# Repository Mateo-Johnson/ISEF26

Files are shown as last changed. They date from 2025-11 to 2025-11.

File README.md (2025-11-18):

Quad Chart

# **EDGE-A/B Overall Design (ESP32-S3-WROOM-1-N16R8)**

**EDGE-A (Expanded Model, General):**

* Dual CPU/MCU System  
  * EDGE-A uses a single ESP32-S3 and a single RP2350 dual-core ARM Cortex-M0+, with the S3 handling high-level coordination, wireless communication (WiFi/Bluetooth), audio processing, data logging, user interface, and system management, while the RP2350 serves as the dedicated real-time processing unit for precise motor control, quadrature encoder processing, sensor fusion (gyroscope \+ TOF), PWM generation, and all timing-critical operations.  
  * The two will communicate over dedicated high speed UART  
* **ESP32-S3 based (ESP32-S3-WROOM-1)**  
  * N16R8  
  * 2.4 GHz Wifi (802.11 b/g/n)  
  * Bluetooth 5.0 (LE)  
  * USB-C (USB4085-GF-A)  
  * Interrupt-capable GPIO pins for encoders/switches  
    * Analog comparators for limit switches  
    * Hardware quadrature encoder inputs (4 channels)  
  * Low-power sleep modes  
    * Light Sleep Mode  
      * CPU is paused, RTC and ULP co-processor are running.  
      * Peripherals (like WiFi, BT) can stay connected.  
      * Wakeup sources: Timer, GPIO, ULP, etc.  
      * Lower power consumption than active mode.  
    * Deep Sleep Mode  
      * CPU, most RAM, and peripherals are powered down.  
      * Only RTC memory and ULP remain active.  
      * Very low power (tens of µA).  
      * Wakeup sources: RTC Timer, GPIO, ULP.  
* **RP2354B**  
  * External 128MB flash memory (W25Q128JVS)  
  * External Crystal (ABM8-272-T3)  
* **I/O OUT \- Check GPIO Diagram**  
  * 10 PIO pins (5 pairs) \- maximizes the RP2354B strength  
  * 2 ADC pins \- essential for motor feedback  
  * I/O can be male/female dupont  
* Distance TOF Sensor (VL53L0CXV0DH1)  
* Gyroscope (ICM-20948)  
  * Motion Interrupted Logging (MIL): only log while moving  
* USB-C/Battery Power  
  * Battery monitoring/protection circuit  
* On-board voltage regulation (3.3V, 5V, GND rails)  
* 3 PWM control channels  
  * 2 integrated DC motor drivers (DRV8833)  
* 3 Servo Connections (GND, 5V, I/O)  
* MicroSD Card Slot (TF-115)  
* 3x RGB LED (WS2812B)  
* Onboard Microphone (ICS-43434)  
* Internal USB hub IC (CH334R)  
  * Single USB-C connector routes to the hub  
  * Hub connects to both ESP32-S3 and RP2354B USB lines  
  * Each processor appears as separate COM ports on computer  
* ~~LoRa/LoRaWAN Communication (Wio-SX1262)~~  
* Battery Charger Circuit (MP2607DL-LF-Z)

**EDGE-B (Expanded Model, Machine Learning):**

* Dual CPU/MCU System  
  * EDGE-B uses a single **ESP32-S3** and a single **Kendryte K210 (Sipeed M1)**, the S3 for high-level planning, sensor fusion (gyro \+ TOF), wireless communication, audio processing, data logging, user interface, and the K210 for AI and ML applications.  
  * The two will communicate over dedicated high speed UART and distribute tasks/share larger pieces of information via shared EEPROM.  
  * Ideally, a MAIX M1 chip would be used instead of a bare K210, but if needed, a bare K210 will do.  
* **ESP32-S3 (ESP32-S3-WROOM-1)**  
  * N16R8  
  * 2.4 GHz Wifi (802.11 b/g/n)  
  * Bluetooth 5.0 (LE)  
  * USB-C (USB4085-GF-A)  
  * Interrupt-capable GPIO pins for encoders/switches  
    * Analog comparators for limit switches  
    * Hardware quadrature encoder inputs (PCNT)  
  * Low-power sleep modes  
    * Light Sleep Mode  
      * CPU is paused, RTC and ULP co-processor are running.  
      * Peripherals (like WiFi, BT) can stay connected.  
      * Wakeup sources: Timer, GPIO, ULP, etc.  
      * Lower power consumption than active mode.  
    * Deep Sleep Mode  
      * CPU, most RAM, and peripherals are powered down.  
      * Only RTC memory and ULP remain active.  
      * Very low power (tens of µA).  
      * Wakeup sources: RTC Timer, GPIO, ULP.  
* **K210 based (Sipeed MAiX module or bare chip)**  
* I/O OUT \- Check GPIO Diagram  
* Camera Input for OV2640 (FPC footprint cable)  
  * Connected to the K210  
* Gyroscope (ICM-20948)  
  * Motion Interrupted Logging (MIL): only log while moving  
* USB-C/Battery Power  
  * Battery monitoring/protection circuit  
* On-board voltage regulation (3.3V, 5V, GND rails)  
* 2 PWM control channels  
  * 2 integrated DC motor drivers (DRV8833)  
* MicroSD Card Slot (TF-115)  
* 3x RGB LED (WS2812B)  
* Onboard Microphone (ICS-43434)  
* EEPROM shared 128MB storage (CAT24M01W)  
* Ribbon Cable Input (OV2640)  
* Internal USB hub IC (CH334R)  
  * Single USB-C connector routes to the hub  
  * Hub connects to both ESP32-S3 and K210 USB lines  
  * Each processor appears as separate COM ports on computer  
* **K210** \- USB-to-UART bridge (CH340N)  
* **K210** will also need a dedicated 16MB of flash storage  
* Battery Charger Circuit (MP2607DL-LF-Z)

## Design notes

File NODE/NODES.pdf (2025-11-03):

# NODE(S):

Nodes are meant to add additional functionality in small form factors, such as extra motor control, AI acceleration, external memory and relays, with more planned in the future. The alphanumeric format (M1, etc.) following the NODE tag is the designation, standing for the functionality of the module, showing the generation/capability level provided by the module. The current planned NODE designations are:
- M = Motor control
- C = Compute Modules
- P = Power management
- N = Network/Communications (CAN, LoRA, etc.)
- D = Display/Interface
- S = Sensors/Input Devices
The NODE system is meant to work with every controller, easily interfacing and being recognized. This means that the NODES will need to have a semi-standardized connector interface. At minimum, all of the nodes in a designation should connect in the same way, +/- a single pin.

# Release 1 NODES:

## - NODE-M1 (✓)

- Motor Module 1 will use a DRV8833PW IC to control a single motor based off of three PWM signals (SLEEP, AIN1, AIN2). The chip will communicate to the board through I/O.

## - NODE-C1 (✓)

- Compute Module 1 will use the Kendryte K210 (MAIX M1) chip for machine learning and artificial intelligence applications. The chip will communicate with the board through I/O (UART).
- The board will have a separate USB-C port, and will need to be programmed separately from the board it is connected to.

## - NODE-C2 (✓)

- Compute Module 2 will use three W25Q128JVS flash modules, used for bulk data storage, firmware updates, data logging, and file system operations, and two 25LC512 EEPROM modules, used for configuration data, calibration settings, user preferences, and frequently-updated system parameters. The chip will communicate with the board through I/O (SPI).

## - NODE-N1 (✓)

- Networking Module 1 will use a GPS module for long range tracking. This chip will communicate to the board through I/O.

## - NODE-N2

- Networking Module 1 will use a LoRa module (SX1276) for long range, low-power communication. This chip will communicate to the board through I/O.

## - NODE-N3

- Networking Module 3 will use a CAN controller (MCP2515) and CAN transceiver (MCP2551) for reliable automotive and industrial bus communication. The chip will communicate to the board through I/O (SPI).

## - NODE-S1

- Environmental Sensors

# Release 1 NODES:

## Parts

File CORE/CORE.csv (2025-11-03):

Id | Designator | Footprint | Quantity | Designation | Supplier and ref
1 | U3 | SOT-23-5 | 1 | AP2112K-3.3
2 | D1 | LED_1206_3216Metric | 1 | LTST-C150RKT
3 | J3,J1 | PinHeader_1x07_P2.54mm_Vertical | 2 | Conn_01x07_Pin
4 | C6,C2,C1,C3 | C0402 | 4 | 100nF
5 | J2 | USB_C_Receptacle_HCTL_HC-TYPE-C-16P-01A | 1 | USB_C_Receptacle_USB2.0_16P
6 | R2,R5,R7,R4,R6,R1 | R0402 | 6 | RC0402FR-075K1L (5.1kΩ)
7 | SW2,SW1 | SW_Push_SPST_NO_Alps_SKRK | 2 | SKRKAGE020
8 | U2 | InvenSense_QFN-24_3x3mm_P0.4mm | 1 | ICM-20948
9 | C4,C7 | C0402 | 2 | 10uF
10 | R3 | R0402 | 1 | RC0402FR-13220RL (220Ω)
11 | U1 | SOT-23 | 1 | AP2127N-1.8
12 | C5 | C0402 | 1 | 22uF
13 | U4 | ESP32-S2-MINI-1 | 1 | ESP32-S3-MINI-1

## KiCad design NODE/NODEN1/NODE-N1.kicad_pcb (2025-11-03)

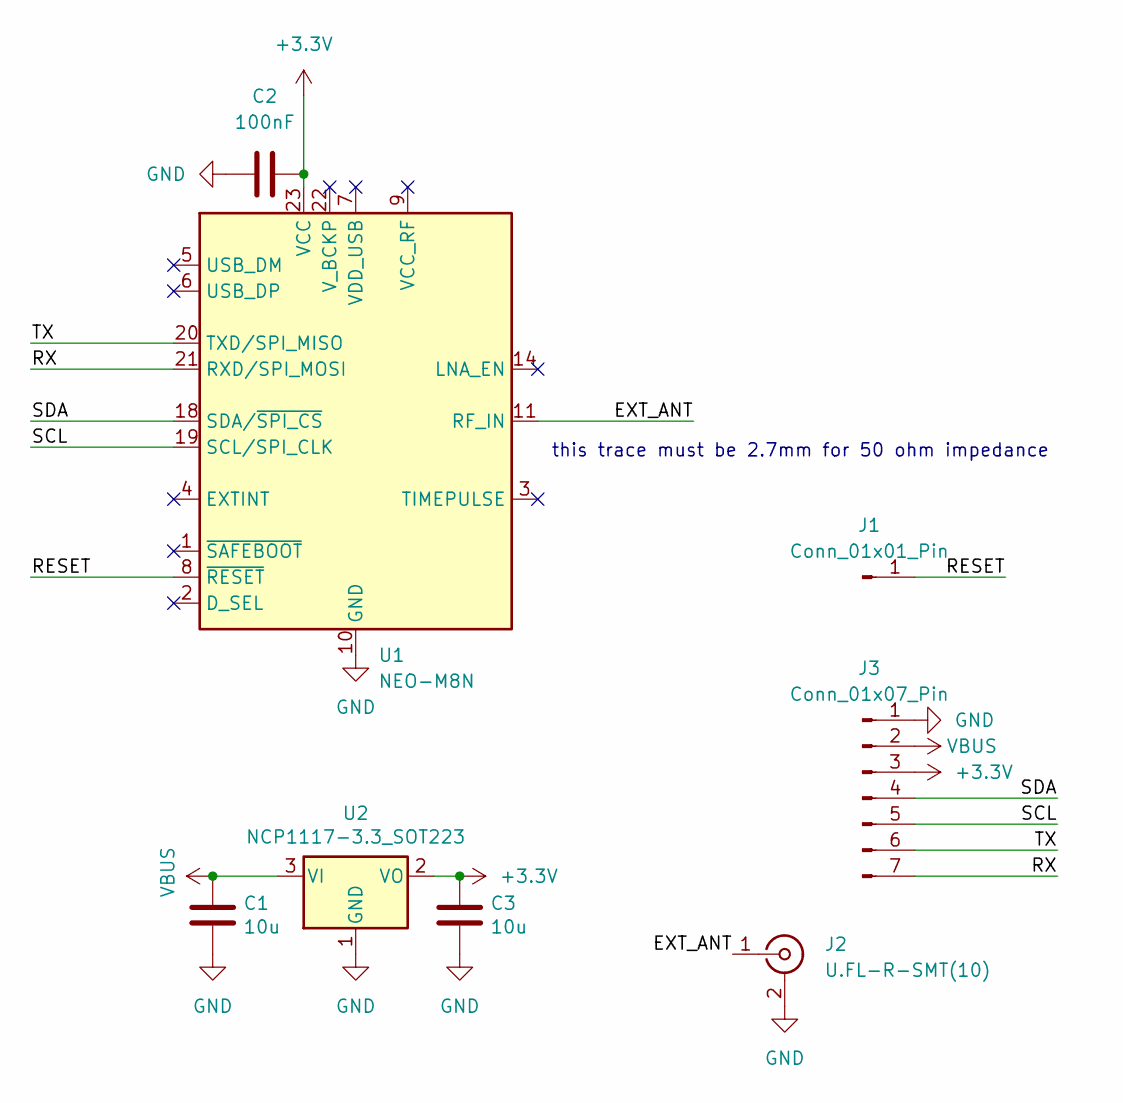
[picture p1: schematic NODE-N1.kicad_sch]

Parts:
C1, C3: 10u; C_0805_2012Metric
C2: 100nF; C0402
J1: Conn_01x01_Pin; TestPoint_Pad_1.5x1.5mm
J2: U.FL-R-SMT(10); U.FL_Hirose_U.FL-R-SMT-1_Vertical
J3: Conn_01x07_Pin; PinHeader_1x07_P2.54mm_Vertical
U1: NEO-M8N; ublox_NEO
U2: NCP1117-3.3_SOT223; SOT-223-3_TabPin2

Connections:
+3.3V: C2.2, C3.1, J3.3, U1.23 (VCC), U2.2 (VO)
/EXT_ANT: J2.1 (In), U1.11 (RF_IN)
/RESET: J1.1, U1.8 (~RESET)
/RX: J3.7, U1.21 (RXD/SPI_MOSI)
/SCL: J3.5, U1.19 (SCL/SPI_CLK)
/SDA: J3.4, U1.18 (SDA/~SPI_CS)
/TX: J3.6, U1.20 (TXD/SPI_MISO)
GND: C1.2, C2.1, C3.2, J2.2 (Ext), J3.1, U1.10 (GND), U1.12 (GND), U1.13 (GND), U1.24 (GND), U2.1 (GND)
VBUS: C1.1, J3.2, U2.3 (VI)

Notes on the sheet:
this trace must be 2.7mm for 50 ohm impedance

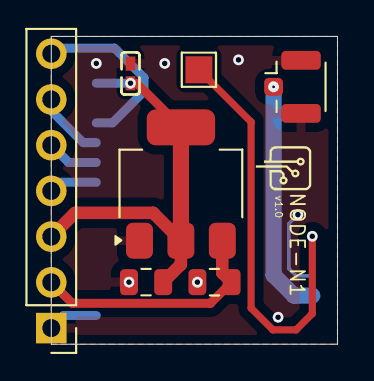
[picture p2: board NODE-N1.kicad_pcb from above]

Board: 2 copper layers, 15.9 x 17.1 mm, 8 parts (1 on the bottom side), 9 nets.

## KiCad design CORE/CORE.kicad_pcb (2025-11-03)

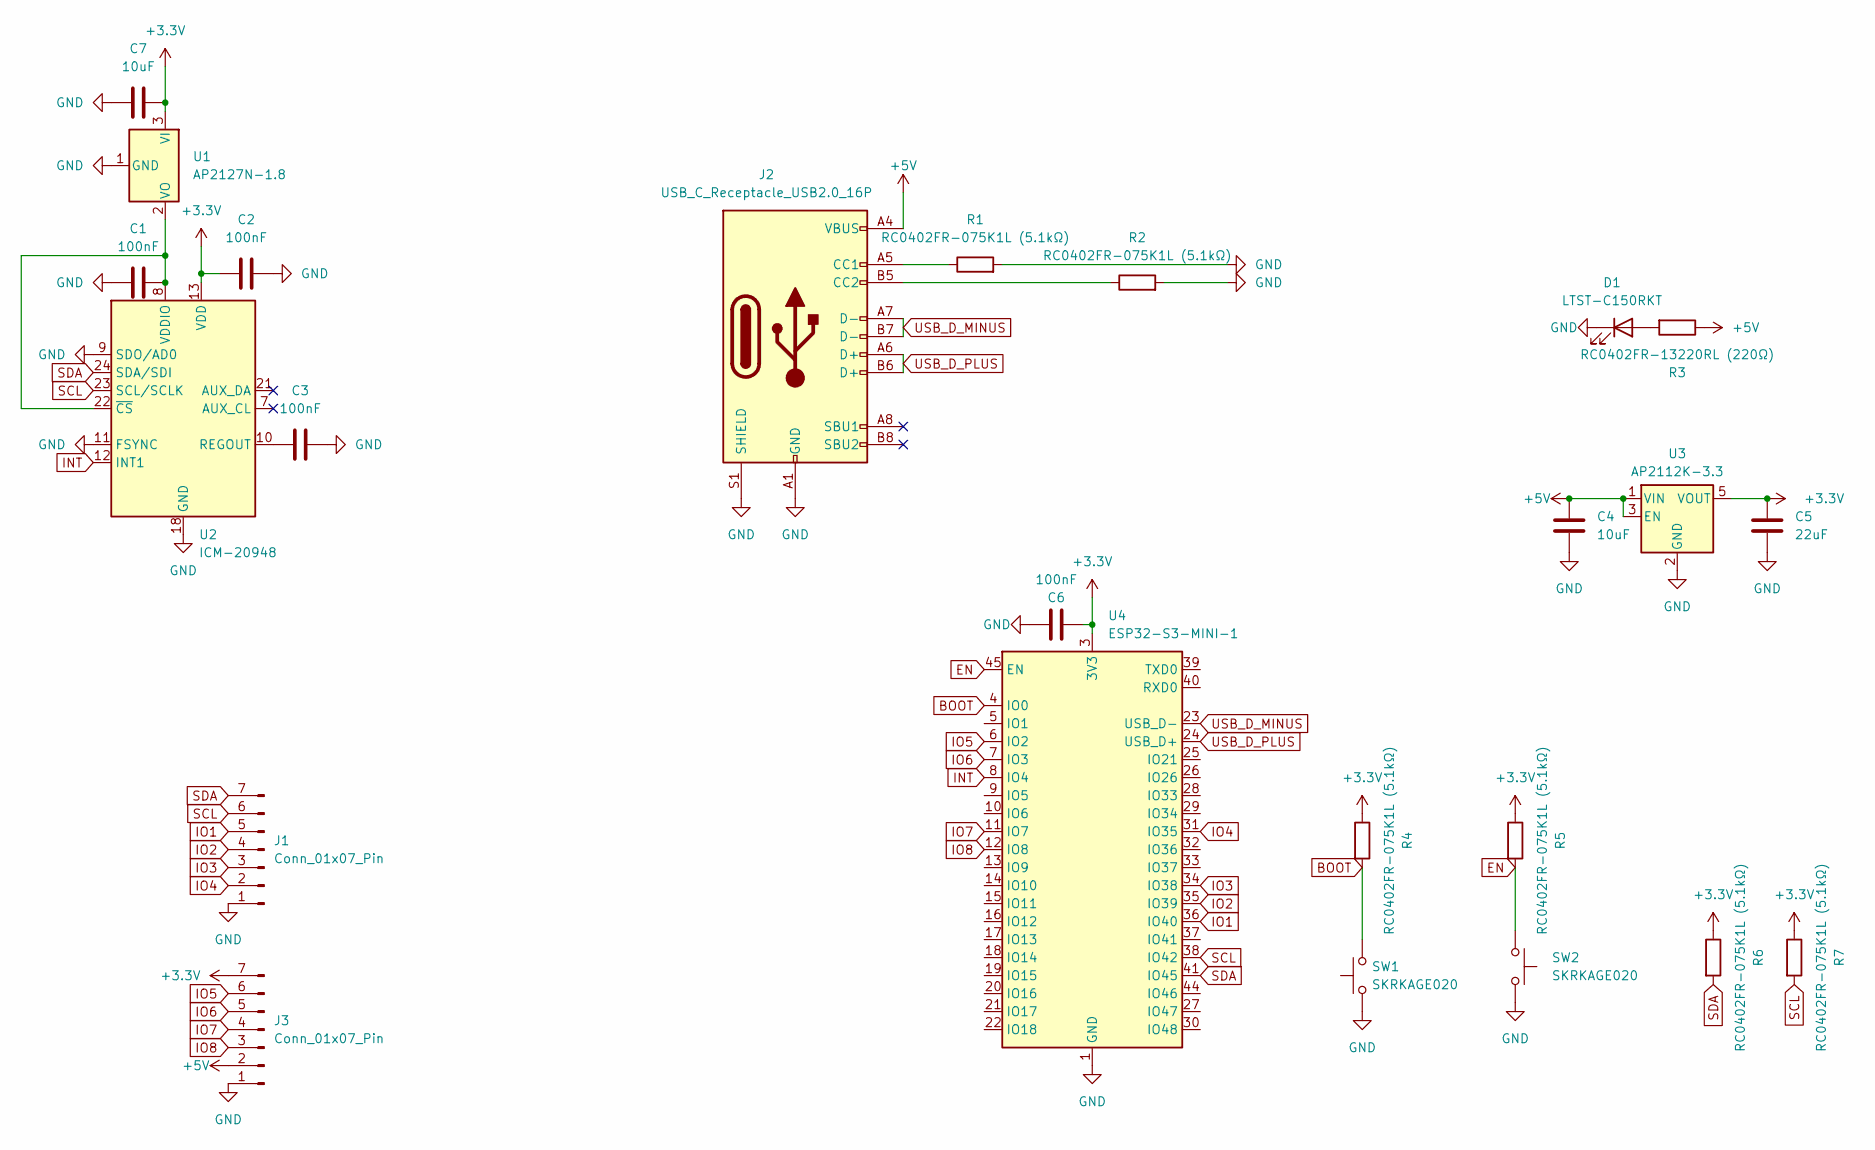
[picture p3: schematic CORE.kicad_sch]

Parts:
C1, C2, C3, C6: 100nF; C0402
C4, C7: 10uF; C0402
C5: 22uF; C0402
D1: LTST-C150RKT; LED_1206_3216Metric
J1, J3: Conn_01x07_Pin; PinHeader_1x07_P2.54mm_Vertical
J2: USB_C_Receptacle_USB2.0_16P; USB_C_Receptacle_HCTL_HC-TYPE-C-16P-01A
R1, R2, R4, R5, R6, R7: RC0402FR-075K1L (5.1kΩ); R0402
R3: RC0402FR-13220RL (220Ω); R0402
SW1, SW2: SKRKAGE020; SW_Push_SPST_NO_Alps_SKRK
U1: AP2127N-1.8; SOT-23
U2: ICM-20948; InvenSense_QFN-24_3x3mm_P0.4mm
U3: AP2112K-3.3; SOT-23-5
U4: ESP32-S3-MINI-1; ESP32-S2-MINI-1

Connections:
+3.3V: C2.1, C5.1, C6.2, C7.2, J3.7, R4.1, R5.1, R6.1, R7.1, U1.3 (VI), U2.13 (VDD), U3.5 (VOUT), U4.3 (3V3)
+5V: C4.1, J2.A4 (VBUS), J2.A9 (VBUS), J2.B4 (VBUS), J2.B9 (VBUS), J3.2, R3.1, U3.1 (VIN), U3.3 (EN)
BOOT: R4.2, SW1.2, U4.4 (IO0)
EN: R5.2, SW2.1, U4.45 (EN)
GND: C1.1, C2.2, C3.2, C4.2, C5.2, C6.1, C7.1, D1.1 (K), J1.1, J2.A1 (GND), J2.A12 (GND), J2.B1 (GND), J2.B12 (GND), J2.S1 (SHIELD), J3.1, R1.2, R2.2, SW1.1, SW2.2, U1.1 (GND), U2.9 (SDO/AD0), U2.11 (FSYNC), U2.18 (GND), U2.20 (GND), U3.2 (GND), U4.1 (GND), U4.2 (GND), U4.42 (GND), U4.43 (GND), U4.46 (GND), U4.47 (GND), U4.48 (GND), U4.49 (GND), U4.50 (GND), U4.51 (GND), U4.52 (GND), U4.53 (GND), U4.54 (GND), U4.55 (GND), U4.56 (GND), U4.57 (GND), U4.58 (GND), U4.59 (GND), U4.60 (GND), U4.61 (GND), U4.62 (GND), U4.63 (GND), U4.64 (GND), U4.65 (GND)
INT: U2.12 (INT1), U4.8 (IO4)
IO1: J1.5, U4.36 (IO40)
IO2: J1.4, U4.35 (IO39)
IO3: J1.3, U4.34 (IO38)
IO4: J1.2, U4.31 (IO35)
IO5: J3.6, U4.6 (IO2)
IO6: J3.5, U4.7 (IO3)
IO7: J3.4, U4.11 (IO7)
IO8: J3.3, U4.12 (IO8)
unnamed: D1.2 (A), R3.2
unnamed: J2.A5 (CC1), R1.1
unnamed: J2.B5 (CC2), R2.1
unnamed: C1.2, U1.2 (VO), U2.8 (VDDIO), U2.22 (~CS)
unnamed: C3.1, U2.10 (REGOUT)
SCL: J1.6, R7.2, U2.23 (SCL/SCLK), U4.38 (IO42)
SDA: J1.7, R6.2, U2.24 (SDA/SDI), U4.41 (IO45)
USB_D_MINUS: J2.A7 (D-), J2.B7 (D-), U4.23 (USB_D-)
USB_D_PLUS: J2.A6 (D+), J2.B6 (D+), U4.24 (USB_D+)

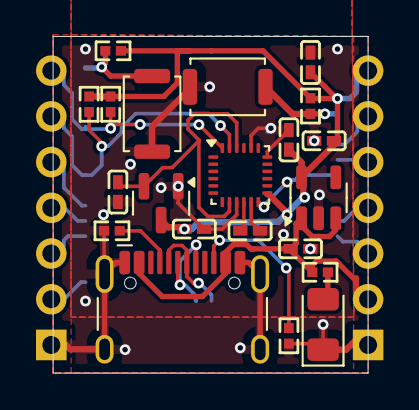
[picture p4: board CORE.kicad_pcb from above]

Board: 2 copper layers, 17.5 x 18.7 mm, 24 parts (1 on the bottom side), 23 nets.

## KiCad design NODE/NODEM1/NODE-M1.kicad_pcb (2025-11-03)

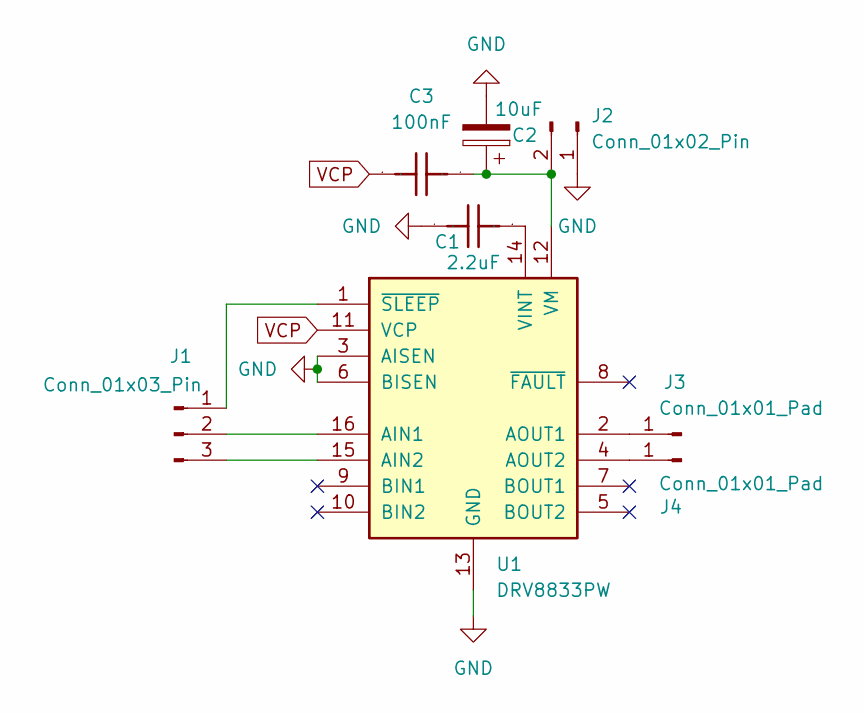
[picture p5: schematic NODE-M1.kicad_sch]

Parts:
C1: 2.2uF; GRM155R60J225KE01D; Manufacturer Part GRM155R60J225KE01D
C2: 10uF; TAJA106K016RNJ
C3: 100nF; CC0805KRX7R9BB104; Manufacturer Part CC0805KRX7R9BB104
J1: Conn_01x03_Pin; PinHeader_1x03_P2.54mm_Vertical
J2: Conn_01x02_Pin; PinHeader_1x02_P2.54mm_Vertical
J3, J4: Conn_01x01_Pad; TestPoint_Pad_1.5x1.5mm
U1: DRV8833PW; TSSOP-16_4.4x5mm_P0.65mm

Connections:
GND: C1.2, C2.2, J2.1, U1.3 (AISEN), U1.6 (BISEN), U1.13 (GND)
unnamed: J1.1, U1.1 (~SLEEP)
unnamed: J1.2, U1.16 (AIN1)
unnamed: J1.3, U1.15 (AIN2)
unnamed: C2.1, C3.2, J2.2, U1.12 (VM)
unnamed: J3.1, U1.2 (AOUT1)
unnamed: J4.1, U1.4 (AOUT2)
unnamed: C1.1, U1.14 (VINT)
VCP: C3.1, U1.11 (VCP)

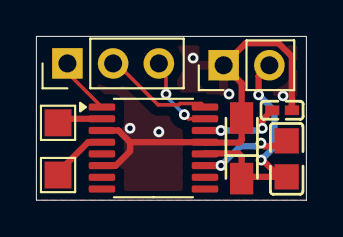
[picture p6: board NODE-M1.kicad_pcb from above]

Board: 2 copper layers, 15.0 x 9.1 mm, 8 parts (0 on the bottom side), 9 nets.

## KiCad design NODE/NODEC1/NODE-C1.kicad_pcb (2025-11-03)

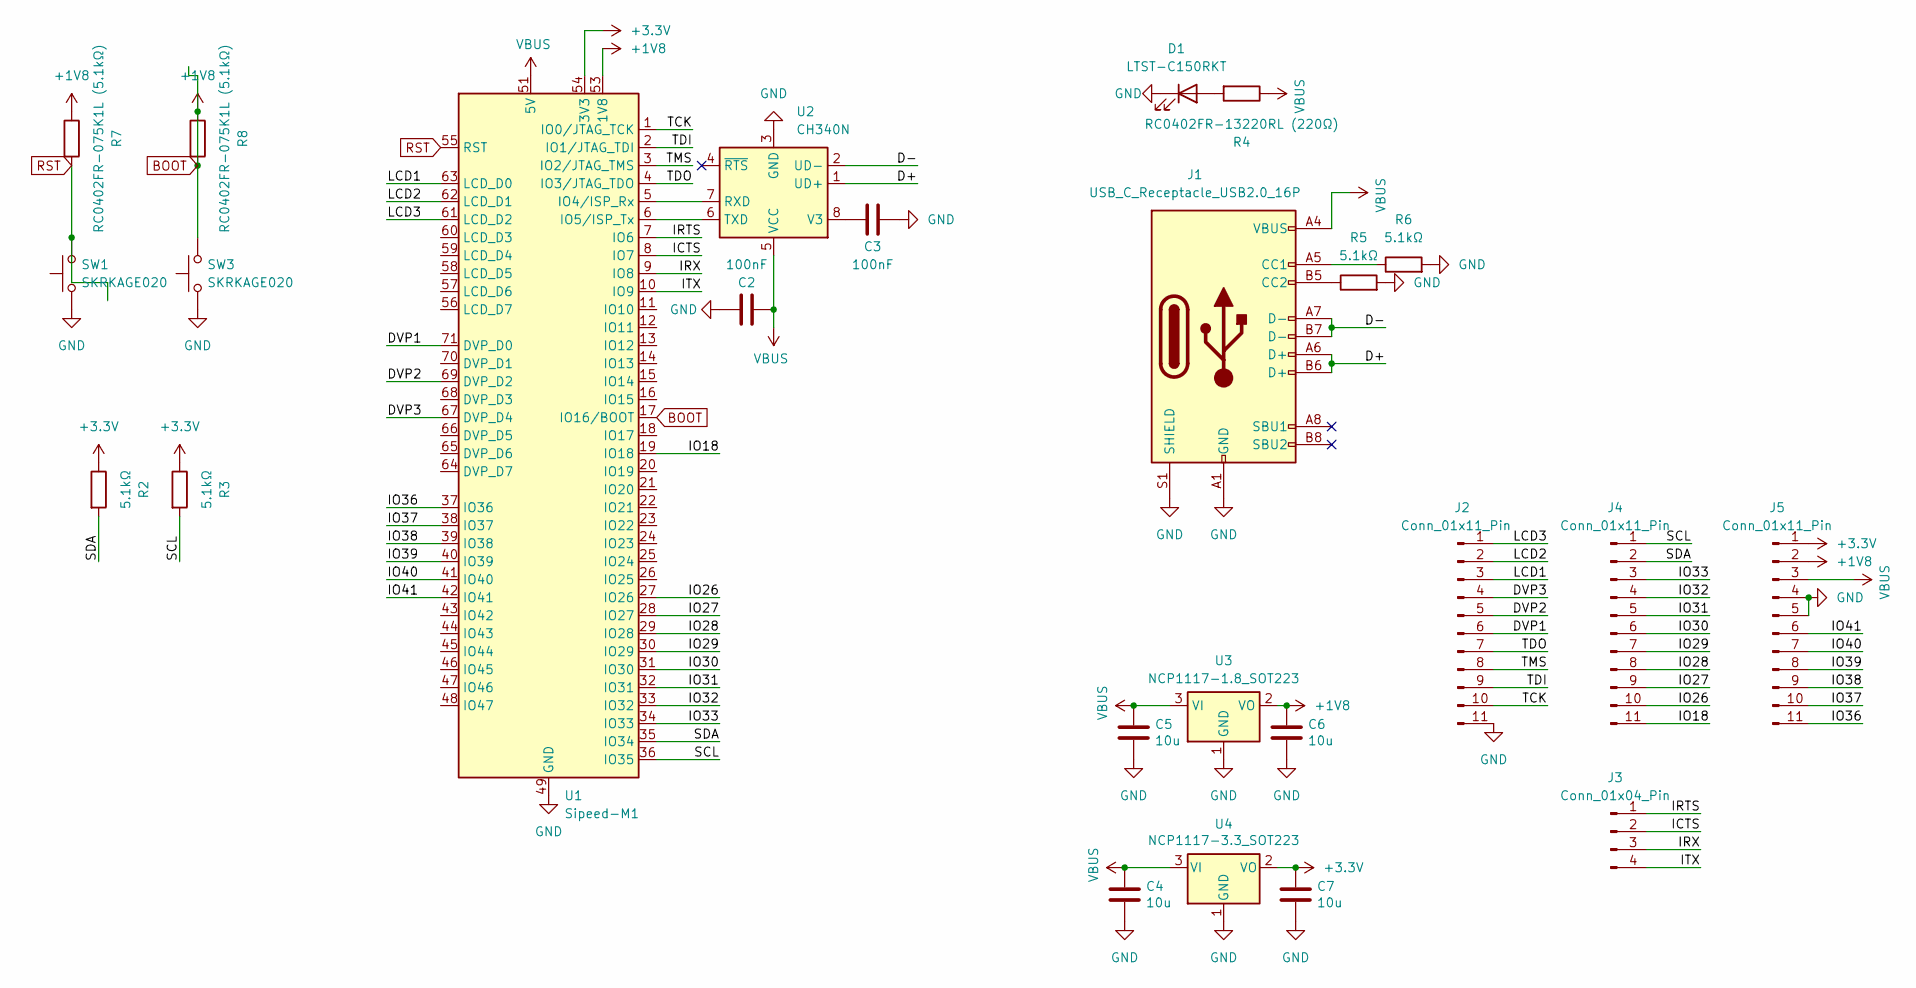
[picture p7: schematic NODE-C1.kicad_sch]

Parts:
C2, C3: 100nF; C0402
C4, C5, C6, C7: 10u; C_0805_2012Metric
D1: LTST-C150RKT; LED_1206_3216Metric
J1: USB_C_Receptacle_USB2.0_16P; USB_C_Receptacle_HCTL_HC-TYPE-C-16P-01A
J2, J4, J5: Conn_01x11_Pin; PinHeader_1x11_P2.54mm_Vertical
J3: Conn_01x04_Pin; PinHeader_1x04_P2.54mm_Vertical
R2, R3, R5, R6: 5.1kΩ; R0402
R4: RC0402FR-13220RL (220Ω); R0402
R7, R8: RC0402FR-075K1L (5.1kΩ); R0402
SW1, SW3: SKRKAGE020; SW_Push_SPST_NO_Alps_SKRK
U1: Sipeed-M1
U2: CH340N; SOP-8_3.9x4.9mm_P1.27mm
U3: NCP1117-1.8_SOT223; SOT-223-3_TabPin2
U4: NCP1117-3.3_SOT223; SOT-223-3_TabPin2

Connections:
+3.3V: C7.1, J5.1, R2.1, R3.1, U1.54 (3V3), U4.2 (VO)
/D+: J1.A6 (D+), J1.B6 (D+), U2.1 (UD+)
/D-: J1.A7 (D-), J1.B7 (D-), U2.2 (UD-)
/DVP1: J2.6, U1.71 (DVP_D0)
/DVP2: J2.5, U1.69 (DVP_D2)
/DVP3: J2.4, U1.67 (DVP_D4)
/ICTS: J3.2, U1.8 (IO7)
/IO18: J4.11, U1.19 (IO18)
/IO26: J4.10, U1.27 (IO26)
/IO27: J4.9, U1.28 (IO27)
/IO28: J4.8, U1.29 (IO28)
/IO29: J4.7, U1.30 (IO29)
/IO30: J4.6, U1.31 (IO30)
/IO31: J4.5, U1.32 (IO31)
/IO32: J4.4, U1.33 (IO32)
/IO33: J4.3, U1.34 (IO33)
/IO36: J5.11, U1.37 (IO36)
/IO37: J5.10, U1.38 (IO37)
/IO38: J5.9, U1.39 (IO38)
/IO39: J5.8, U1.40 (IO39)
/IO40: J5.7, U1.41 (IO40)
/IO41: J5.6, U1.42 (IO41)
/IRTS: J3.1, U1.7 (IO6)
/IRX: J3.3, U1.9 (IO8)
/ITX: J3.4, U1.10 (IO9)
/LCD1: J2.3, U1.63 (LCD_D0)
/LCD2: J2.2, U1.62 (LCD_D1)
/LCD3: J2.1, U1.61 (LCD_D2)
/SCL: J4.1, R3.2, U1.36 (IO35)
/SDA: J4.2, R2.2, U1.35 (IO34)
/TCK: J2.10, U1.1 (IO0/JTAG_TCK)
/TDI: J2.9, U1.2 (IO1/JTAG_TDI)
/TDO: J2.7, U1.4 (IO3/JTAG_TDO)
/TMS: J2.8, U1.3 (IO2/JTAG_TMS)
GND: C2.1, C3.1, C4.2, C5.2, C6.2, C7.2, D1.1 (K), J1.A1 (GND), J1.A12 (GND), J1.B1 (GND), J1.B12 (GND), J1.S1 (SHIELD), J2.11, J5.4, J5.5, R5.2, R6.2, SW1.1, SW3.1, U1.49 (GND), U1.50 (GND), U1.72 (GND), U2.3 (GND), U3.1 (GND), U4.1 (GND); also elsewhere on the board
unnamed: D1.2 (A), R4.2
unnamed: J1.A5 (CC1), R6.1
unnamed: J1.B5 (CC2), R5.1
unnamed: U1.5 (IO4/ISP_Rx), U2.7 (RXD)
unnamed: U1.6 (IO5/ISP_Tx), U2.6 (TXD)
unnamed: C3.2, U2.8 (V3)
RST: R7.2, SW1.2, U1.55 (RST); also elsewhere on the board
VBUS: C2.2, C4.1, C5.1, J1.A4 (VBUS), J1.A9 (VBUS), J1.B4 (VBUS), J1.B9 (VBUS), J5.3, R4.1, U1.51 (5V), U1.52 (5V), U2.5 (VCC), U3.3 (VI), U4.3 (VI)

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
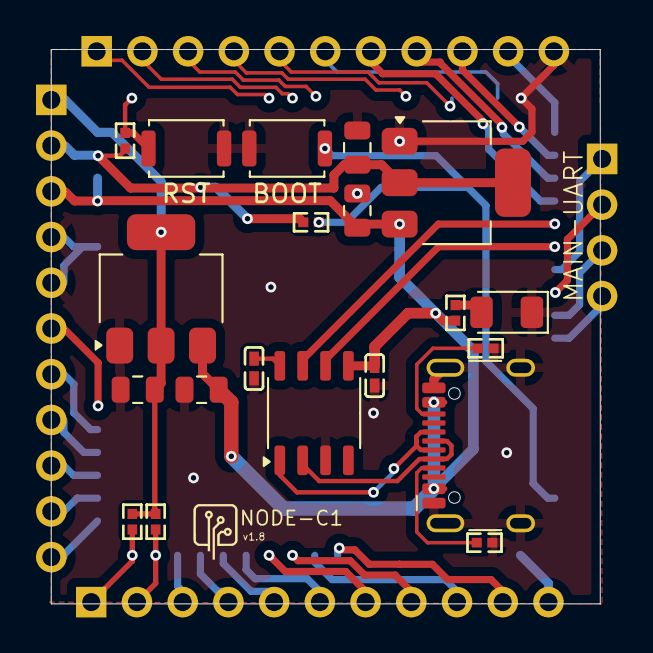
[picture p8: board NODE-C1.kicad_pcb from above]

Board: 2 copper layers, 30.5 x 30.8 mm, 25 parts (1 on the bottom side), 45 nets.

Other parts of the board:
BOOT: SKRKAGE020; SW_Push_SPST_NO_Alps_SKRK
RST: SKRKAGE020; SW_Push_SPST_NO_Alps_SKRK

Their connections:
GND: BOOT.1, RST.1; also elsewhere on the board
RST: RST.2; also elsewhere on the board

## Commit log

2025-11-03 add node C1 files
    [NODE-C1.kicad_pcb, NODE-C1.kicad_sch]
2025-11-03 Add files via upload
    add node m1 files
    [NODE-M1.kicad_pcb, NODE-M1.kicad_sch]
